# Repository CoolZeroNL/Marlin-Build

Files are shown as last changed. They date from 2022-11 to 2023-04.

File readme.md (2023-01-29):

Build Pipeline for marlin, is currently building from bugfix-2.1.x for the following machines:

- Wanhao dublicator D6
- Wanhao dublicator 4S
- Wanhao dublicator i3 plus
- Wanhao dublicator v2.1
- Creality CR10 S4

# Octoprint - Bed Visualizer
```
G28 X Y               ; home X & Y
M140 S60              ; starting by heating the bed for nominal mesh accuracy
M104 S190             ; heat nozzle
M190 S60              ; waiting until the bed is fully warmed up
M109 S190             ; wait for nozzle to heat up
G28 Z                 ; home Z
M155 S0             ; stop temperature reporting rate to reduce output pollution
@BEDLEVELVISUALIZER	; tell the plugin to watch for reported mesh
G29 T	            ; run bilinear probing
M155 S3             ; reset temperature reporting
M500                  ; store mesh in EEPROM
```

M104 S[extruder[new_tool]_temperature] T[new_tool] 	; warm extruder
M140 S[bed[new_tool] _temperature] 		; warm bed

M109 S[extruder[new_tool]_temperature] T[new_tool] 	; wait extruder to reach temp
M190 S[bed[new_tool] _temperature] 		; wait bed to reach temp

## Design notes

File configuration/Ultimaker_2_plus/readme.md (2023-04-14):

# How to upgrade Firmware
- https://support.makerbot.com/s/article/1667337917778

use cura, also to return to stock firmware.

# Current:

Marlin 1.0.0
Last Updated: Mar 15 2018 13:04:08 | Author: Vers:_3.3.0
Free Memory: 2055  PlannerBufferBytes: 1232
Stored settings retrieved

Steps per unit:
M92 X80.00 Y80.00 Z200.00 E369.00

Maximum feedrates (mm/s):
M203 X300.00 Y300.00 Z40.00 E45.00

Maximum Acceleration (mm/s2):
M201 X9000 Y9000 Z100 E10000

Acceleration: S=acceleration, T=retract acceleration
M204 S3000.00 T3000.00

Advanced variables: S=Min feedrate (mm/s), T=Min travel feedrate (mm/s), B=minimum segment time (ms), X=maximum XY jerk (mm/s),  Z=maximum Z jerk (mm/s),  E=maximum E jerk (mm/s)
M205 S0.00 T0.00 B20000 X20.00 Z0.40 E5.00

Home offset (mm):
M206 X0.00 Y0.00 Z-14.05

PID settings:
M301 P10.03 I1.50 D70.00

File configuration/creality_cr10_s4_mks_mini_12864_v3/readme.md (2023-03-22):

see other CR10 S4 for other details.

# MKS LCD

- https://github.com/makerbase-mks/MKS-MINI12864-V3

## Connect
- Connect to MKS board by EXP1 and EXP2
- Connect to other board by EXP1 and EXP1, but cable need Rotate 180°
- 

## Marlin2.0

in Configuration.h file

``` 
Enable: #define MKS_MINI_12864_V3
Enable: #define NEOPIXEL_LED
Change: #define NEOPIXEL_TYPE NEO_GRBW --> NEO_RGB
``` 

Change color by lcd display on the machine: Lights -> Light Presets

# Z-Offset Instructions:
```
G28 Z       // Home 3D printer
M851 Z0     // Reset Z0Offset
M500        // Store setting to eeprom
M501        // Set active parameters
G28 Z       // Home Z Axis
G1 F60 Z0   // Move nozzle to true 0 offset
M211 S0     // Switch off soft endstops
```

- Move nozzle towards bed slowly until the paper can barely move
- Take note of the Z on the printer display (take that number and add the measurment of the calibration sheet or device used)

```
M851 Z -1.9
M211 S1     // Enable Soft Endstops
M500        // Save settings to Eeprom
M501        // Set Active Parameters
```

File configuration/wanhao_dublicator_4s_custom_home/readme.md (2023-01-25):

# How to flash

Use the atmega 1280 ISP pin headers on the mainboard
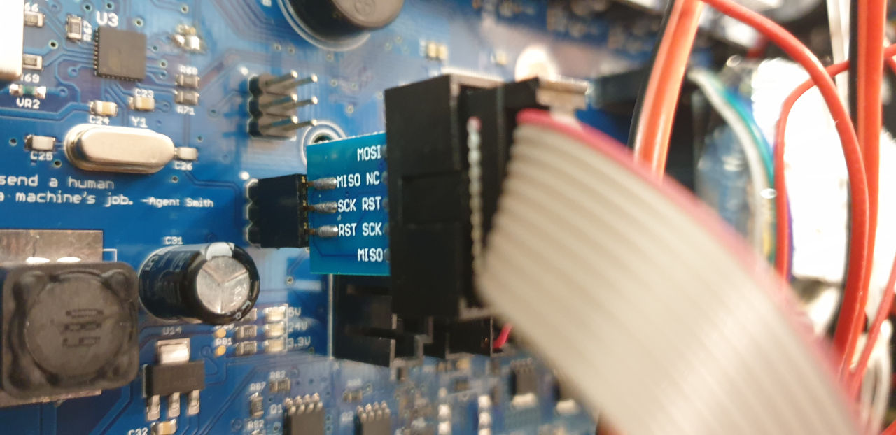
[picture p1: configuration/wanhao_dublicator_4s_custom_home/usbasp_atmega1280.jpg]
This is an image


## Marlin Flash command: 
``` 
avrdude -p m1280 -c usbasp -e -U flash:w:firmware.hex
avrdude -p m1280 -c usbasp -e -U flash:w:firmware_c16d365_c16d3655bf_wanhao_dublicator_4s.hex
```

# Building @ platformm.io
The BOARD_MIGHTYBOARD_REVE is special, it uses pin that are not in the arduino build env. Use build env MightyBoard1280

## Orsinal Sailfish
```
# one 
# Please connect USBASP to motherbaord  8U2  ICSP1
avrdude -p at90usb82 -F -P usb -c usbasp -U lock:w:0x0F:m -U efuse:w:0xF4:m -U hfuse:w:0xD9:m -U lfuse:w:0xff:m -Uflash:w:Makerbot-usbserial.hex

# two
# Connect USBasp to 1280 ICSP2
avrdude -p m1280 -F -P usb -c usbasp -U flash:w:ATmegaBOOT_168_atmega1280.hex -U lfuse:w:0xff:m -U hfuse:w:0xD8:m -U efuse:w:0xF5:m -U lock:w:0x3F:m
```

# WARNING !!
firware is adjuded that the Y MAX LIMIT SWITCH is in the front of the machine, and not on its orginal place!

# USer Fans
NUM_M106_FANS is set to 1, and on build is a custom pins file used!

# Backup of Sailfish settings:

```xml
System Information
 ReplicatorG version: 0040
 Java version: 1.6.0_16

Machine
 Profile Name: The Replicator Dual
 Driver Type: MightyBoard
 Name: Wanhao Duplicatr
 Motherboard firmware version: Unknown v7.7
 Motherboard communication statistics
  Number of packets received from the USB interface:0
  Number of packets sent over the RS485 interface:0
  Number of packets sent over the RS485 interface that were not responded to:0
  Number of packet retries attempted:0
  Number of bytes received over the RS485 interface that were discarded as noise:0

Machine Driver XML:
<machine experimental="0">
		<name>The Replicator Dual</name>
		<geometry type="cartesian">
			<!-- different pulleys on X and Y axii -->
			<axis endstops="max" homingfeedrate="2500" id="x" length="227" maxfeedrate="18000" stepspermm="94.139704"/>  <!-- Pulley dia: 10.82mm / 1/8 step = 1/(10.82 * pi / 1600) -->
			<axis endstops="max" homingfeedrate="2500" id="y" length="148" maxfeedrate="18000" stepspermm="94.139704"/>  <!-- Pulley dia: 10.82mm / 1/8 step = 1/(10.82 * pi / 1600) -->
			<axis endstops="min" homingfeedrate="1100" id="z" length="150" maxfeedrate="1170" stepspermm="400"/> <!-- Actual length is 157mm, we reserve ~5mm for safety. TR-8x8 Z axis = 1/(8/1600) -->
			<axis endstops="none" id="a" length="100000" maxfeedrate="1600" stepspermm="96.275201870333662468889989185642"/> <!-- stepspermm is incoming filament length, see comment at bottom for explanation -->
			<axis endstops="none" id="b" length="100000" maxfeedrate="1600" stepspermm="96.275201870333662468889989185642"/> <!-- stepspermm is incoming filament length, see comment at bottom for explanation -->
		</geometry>
		<tools>
			<tool default_rpm="3" diameter="0.4" fan="true" heatedplatform="false" heater="true" index="1" model="Mk8" motor="true" motor_steps="3200" name="Mk8 Left" stepper_axis="b" type="extruder"/>
			<tool default_rpm="3" diameter="0.4" fan="true" heatedplatform="true" heater="true" index="0" model="Mk8" motor="true" motor_steps="3200" name="Mk8 Right" stepper_axis="a" type="extruder"/>
		</tools>
		<wipes>
			<wipe X1="-135.0" X2="-135.0" Y1="55.0" Y2="45.0" index="0" purge_duration="1000" purge_rpm="5.0" reverse_duration="15" reverse_rpm="35.0" wait="1000.0"/>
			<wipe X1="-135.0" X2="-135.0" Y1="55.0" Y2="45.0" index="1" purge_duration="1000" purge_rpm="5.0" reverse_duration="15" reverse_rpm="35.0" wait="1000.0"/>
		</wipes>
		<offsets>
			<offset xNozzle="33.0" yNozzle="0.0" zNozzle="0.0"/>
		</offsets>
		<clamps/>
		<driver name="mightyboard">
			<!-- optional: <portname>COM1</portname> -->
			<rate>115200</rate>
		</driver>
		<warmup>
		</warmup>
		<cooldown>
M18 (Turn off steppers after a build.)
		</cooldown>
		<bookend dualstart="machines/replicator/Dualstrusion_start.gcode" end="machines/replicator/Dual_Head_end.gcode" start="machines/replicator/Dual_Head_start.gcode"/>
	</machine>
```

        <!-- Dualstrusion_start.gcode -->
        (**** start.gcode for The Replicator, Dualstrusion! ****)
        M103 (disable RPM)
        M73 P0 (enable build progress)
        G21 (set units to mm)
        G90 (set positioning to absolute)
        M109 S110 T0 (set HBP temperature)
        M104 S220 T0 (set extruder temperature)
        M104 S220 T1 (set extruder temperature)
        (**** begin homing ****)
        G162 X Y F2500 (home XY axes maximum)
        G161 Z F1100 (home Z axis minimum)
        G92 Z-5 (set Z to -5)
        G1 Z0.0 (move Z to "0")
        G161 Z F100 (home Z axis minimum)
        M132 X Y Z A B (Recall stored home offsets for XYZAB axis)
        (**** end homing ****)
        G1 X-110.5 Y-74 Z50 F3300.0 (move to waiting position)
        G130 X20 Y20 Z20 A20 B20 (Lower stepper Vrefs while heating)
        M6 T0 (wait for toolhead, and HBP to reach temperature)
        M6 T1 (wait for toolhead, and HBP to reach temperature)
        G130 X127 Y127 Z40 A127 B127 (Set Stepper motor Vref to defaults)
        G0 X-110.5 Y-74     (Position Nozzle)
        G0 Z0.6         (Position Height)
        G1 E4 F50.0      (Create Anchor)
        G92 E0
        (**** end of start.gcode ****)

        <!-- Dual_Head_end.gcode -->
        (******* End.gcode*******)
        M73 P100 ( End  build progress )
        G0 Z150 ( Send Z axis to bottom of machine )
        M18 ( Disable steppers )
        M109 S0 T0 ( Cool down the build platform )
        M104 S0 T0 ( Cool down the Right Extruder )
        M104 S0 T1 ( Cool down the Left Extruder )
        G162 X Y F2500 ( Home XY endstops )
        M18 ( Disable stepper motors )
        M70 P5 ( We <3 Making Things!)
        M72 P1  ( Play Ta-Da song )
        (*********end End.gcode*******)

        <!-- Dual_Head_start.gcode -->
        (**** start.gcode for The Replicator, dual head ****)
        M103 (disable RPM)
        M73 P0 (enable build progress)
        G21 (set units to mm)
        G90 (set positioning to absolute)
        M109 S110 T0 (set HBP temperature)
        M104 S220 T0 (set extruder temperature)
        (**** begin homing ****)
        G162 X Y F2500 (home XY axes maximum)
        G161 Z F1100 (home Z axis minimum)
        G92 Z-5 (set Z to -5)
        G1 Z0.0 (move Z to "0")
        G161 Z F100 (home Z axis minimum)
        M132 X Y Z A B (Recall stored home offsets for XYZAB axis)
        (**** end homing ****)
        G1 X-110.5 Y-74 Z150 F3300.0 (move to waiting position)
        G130 X20 Y20 Z20 A20 B20 (Lower stepper Vrefs while heating)
        M6 T0 (wait for toolhead, and HBP to reach temperature)
        G130 X127 Y127 Z40 A127 B127 (Set Stepper motor Vref to defaults)
        M108 R3.0 T0
        G0 X-110.5 Y-74 (Position Nozzle)
        G0 Z0.6      (Position Height)
        M108 R5.0    (Set Extruder Speed)
        M101         (Start Extruder)
        G4 P2000     (Create Anchor)
        (**** end of start.gcode ****)

        <!-- Single_Head_end.gcode -->
        (******* End.gcode*******)
        M73 P100 ( End  build progress )
        G0 Z150 ( Send Z axis to bottom of machine )
        M18 ( Disable steppers )
        M104 S0 T0 ( Cool down the Right Extruder )
        M109 S0 T0 ( Cool down the platform)
        G162 X Y F2500 ( Home XY endstops )
        M18 ( Disable stepper motors )
        M70 P5 ( We <3 Making Things!)
        M72 P1  ( Play Ta-Da song )
        (*********end End.gcode*******)

        <!-- Single_Head_start.gcode -->
        (**** start.gcode for The Replicator, single head ****)
        M103 (disable RPM)
        M73 P0 (enable build progress)
        G21 (set units to mm)
        G90 (set positioning to absolute)
        M109 S110 T0 (set HBP temperature)
        M104 S220 T0 (set extruder temperature)
        (**** begin homing ****)
        G162 X Y F2500 (home XY axes maximum)
        G161 Z F1100 (home Z axis minimum)
        G92 Z-5 (set Z to -5)
        G1 Z0.0 (move Z to "0")
        G161 Z F100 (home Z axis minimum)
        M132 X Y Z A B (Recall stored home offsets for XYZAB axis)
        (**** end homing ****)
        G1 X-110.5 Y-74 Z150 F3300.0 (move to waiting position)
        G130 X20 Y20 Z20 A20 B20 (Lower stepper Vrefs while heating)
        M6 T0 (wait for toolhead, and HBP to reach temperature)
        G130 X127 Y127 Z40 A127 B127 (Set Stepper motor Vref to defaults)
        M108 R3.0 T0
        G0 X-110.5 Y-74 (Position Nozzle)
        G0 Z0.6      (Position Height)
        M108 R5.0    (Set Extruder Speed)
        M101         (Start Extruder)
        G4 P2000     (Create Anchor)
        (**** end of start.gcode ****)

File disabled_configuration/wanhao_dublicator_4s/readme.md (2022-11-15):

Special note for dual/multi extrusion
By default, Marlin expects the e-steps for each of your extruders to be the same. To work around this, you must compile with DISTINCT_E_FACTORS uncommented/enabled in configuration.h:

You will then be able to enter a unique M92 value for each extruder.

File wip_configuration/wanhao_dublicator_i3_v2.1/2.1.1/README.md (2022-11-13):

Configuration for the Wanhao Duplicator i3 v2.1

[Made by Bot-In-a-Box Educational Robotics](https://botinabox.ca)
[See original configuration repo](https://github.com/BotInABoxER/marlin2-for-wanhao-i3)

Notes:
- YMMV, but the included thermistor table has been tested to work with a 100k bed thermistor with a 10K pull-up resistor
- The smaller Marlin logo is used to save memory
- You may have a 4.7K pull-up resistor, in which case the included thermistor table will be off
- The included thermistor table was generated with `buildroot/share/scripts/createTemperatureLookupMarlin.py --rp=10000`
- Includes an optional custom Wanhao logo bootscreen designed to fit the stock LCD

Inspirations:
- https://www.thingiverse.com/thing:3378807 (Custom firmware 1.x by Nitrogen777)
- https://www.thingiverse.com/thing:3378807 (Custom firmware 2.x by Remotheman)

Some Features:
Built-in Thermal Runway Protection
Change Settings and Save/Load them from EEPROM
Printing over SD Micro/USB Mini Support
Custom Thermistor Table (99) made using buildroot/share/scripts/createTemperatureLookupMarlin.py for 10k pull-up resistor with the out-of-the-box thermistor
Print Time Elapsed and Progress Bar
Minor Stability/Connection/Performance Improvements

Instructions:
- Copy the `Configuration.h`, `_Bootscreen.h` and `Configuration_adv.h` to the `Marlin/ directory`
- Copy the `thermistor_99.h` and `thermistors.h` files to the `Marlin/src/modules/thermistors` directory
- Flash the firmware onto your Melzi (https://www.fission3d.com/guides/flash-bootloader-and-install-firmware-with-raspberry-pi might help)

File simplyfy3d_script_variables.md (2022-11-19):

<!-- https://forum.simplify3d.com/viewtopic.php?t=3144&start=10 -->

<!-- TOC -->

- [Starting script](#starting-script)
- [Ending script](#ending-script)
- [Retraction script](#retraction-script)
- [Tool change script](#tool-change-script)
- [Post processing](#post-processing)

<!-- /TOC -->

# Starting script

A custom G code to be inserted at the very beginning. All speeds should be entered in mm / min.

You can use predefined variables:
| Variable | Comment |
| --- | --- |
| extruder # _temperature | nozzle temperature, where # є [0..5] (only certain ones are substituted, c 4.1 - '-1'); |
| bed # _temperature | table temperature, where # є [0..5] (only certain ones are substituted, c 4.1 - '-1');  |
| fan_speed_percentage | fan speed in percent [0..100]; |
| fan_speed_pwm | fan speed [0..255]; |
| progress | percentage of print (always like 0). |

Since version 4.1, added variables:
| Variable | comment |
| --- | --- |
| current_feature_type | element type, one of (travel, outer_perimeter, inner_perimeter, external_single_extrusion, internal_single_extrusion, gap_fill, solid_layer, infill, bridge, support, dense_support, raft, skirt, prime_pillar, ooze_shield); |
| current_layer | the current layer; |
| current_layer_height | current layer height; |
| current_position_ $ | the current coordinates of the $ axis, where $ є [xyze]; |
| current_position_e # | the current coordinates of the axis of the extruder, where # є [0..5]; |
| next_position_ $ | the following coordinates of the $ axis, where $ є [xyz]; |
| current_tool | current nozzle; |
| first_tool | not clear; |
| last_tool | it is not clear; |
| prime_distance | extrusion distance after retraction; |
| prime_speed | extrusion speed after retraction, mm / min; |
| retract_distance | retraction distance; |
| retract_speed | retraction speed, mm / min; |
| retract_vertical_lift | rising nozzle after retraction; |
| toolchange_prime_distance | extrusion distance after retraction when changing the nozzle; |
| toolchange_prime_speed | extrusion speed after retraction when changing the nozzle, mm / min; |
| toolchange_retract_distance | retraction distance when changing the nozzle; |
| toolchange_retract_speed | retraction speed when changing the nozzle, mm / min; |
| xy_travel_speed | speed of movement along the xy axes, mm / min; |
| z_travel_speed | speed of movement along the z axis, mm / min; |
| travel_speed | travel speed, mm / min; |
| chamber # _temperature | it is not clear where # є [0..5]; |
| fan # _speed_percentage | it is not clear where # є [0..5]; |
| fan # _speed_pwm | it is not clear where # є [0..5]; |
| total_filament_used | length of the used bar; |
| total_filament_weight | weight of the bar used; |
| total_filament_cost | the cost of the used bar; |
| total_filament_volume | the volume of the used bar; |
| total_print_time_min | print time in minutes; |
| total_print_time_sec | print time in seconds; |
| total_layer_count | the number of layers; |
| build_min_ $ | the minimum coordinate of the part along the axis, where $ є [xyz]; |
| build_max_ $ | the maximum coordinate of the part along the axis, where $ є [xyz]; |
| build_size_ $ | the size of the part along the axis, where $ є [xyz]; |
| extruder # _filament_used | the length of the rod used for the extruder, where # є [0..5]; |
| extruder # _filament_weight | the weight of the rod used for the extruder, where # є [0..5]; |
| extruder # _filament_cost | the cost of the rod used for the extruder, where # є [0..5]; |
| extruder # _filament_volume | the volume of the rod used for the extruder, where # є [0..5]. |

Since version 4.1, added operators:
- {EVAL "xxx"} - the number xxx removes the last 0 and then the last '.'. For example, from 10,000 there will be 10, where xxx expression (using QJSEngine.toNumber (), JavaScript code interpreter);
- {IF "xxx"} zzz - when condition xxx is fulfilled, zzz is displayed, where xxx expression (used by QJSEngine.toBool (), JavaScript code interpreter). 

# Ending script

You can use predefined variables:
| Variable | Comment |
| --- | --- |
| current_Z_position | Z coordinates; |
| progress | percentage of print (always like 100). |

Since version 4.1, added variables:
| Variable | Comment |
| --- | --- |
| extruder # _temperature | nozzle temperature or -1, where # є [0..5]; |
| bed # _temperature | table temperature or -1, where # є [0..5]; |
| chamber # _temperature | it is not clear or -1, where # є [0..5]; |
| fan_speed_percentage | fan speed in percent [0..100]; |
| fan_speed_pwm | fan speed [0..255]; |
| fan # _speed_percentage | it is not clear where # є [0..5]; |
| fan # _speed_pwm | it is not clear where # є [0..5]; |
| current_feature_type | element type, one of (travel, outer_perimeter, inner_perimeter, external_single_extrusion, internal_single_extrusion, gap_fill, solid_layer, infill, bridge, support, dense_support, raft, skirt, prime_pillar, ooze_shield); |
| current_layer | the current layer; |
| current_layer_height | current layer height; |
| current_position_ $ | the current coordinates of the $ axis, where $ є [xyze]; |
| current_position_e # | the current coordinates of the axis of the extruder, where # є [0..5]; |
| next_position_ $ | the following coordinates of the $ axis, where $ є [xyz]; |
| current_tool | current nozzle; |
| first_tool | not clear; |
| last_tool | it is not clear; |
| prime_distance | extrusion distance after retraction; |
| prime_speed | extrusion speed after retraction, mm / min; |
| retract_distance | retraction distance; |
| retract_speed | retraction speed, mm / min; |
| retract_vertical_lift | rising nozzle after retraction; |
| toolchange_prime_distance | extrusion distance after retraction when changing the nozzle; |
| toolchange_prime_speed | extrusion speed after retraction when changing the nozzle, mm / min; |
| toolchange_retract_distance | retraction distance when changing the nozzle; |
| toolchange_retract_speed | retraction speed when changing the nozzle, mm / min; |
| xy_travel_speed | speed of movement along the xy axes, mm / min; |
| z_travel_speed | speed of movement along the z axis, mm / min; |
| travel_speed | travel speed, mm / min; |
| total_filament_used | length of the used bar; |
| total_filament_weight | weight of the bar used; |
| total_filament_cost | the cost of the used bar; |
| total_filament_volume | the volume of the used bar; |
| total_print_time_min | print time in minutes; |
| total_print_time_sec | print time in seconds; |
| total_layer_count | the number of layers; |
| build_min_ $ | the minimum coordinate of the part along the axis, where $ є [xyz]; |
| build_max_ $ | the maximum coordinate of the part along the axis, where $ є [xyz]; |
| build_size_ $ | the size of the part along the axis, where $ є [xyz]; |
| extruder # _filament_used | the length of the rod used for the extruder, where # є [0..5]; |
| extruder # _filament_weight | the weight of the rod used for the extruder, where # є [0..5]; |
| extruder # _filament_cost | the cost of the rod used for the extruder, where # є [0..5]; |
| extruder # _filament_volume | the volume of the rod used for the extruder, where # є [0..5]. |

Since version 4.1, added operators:
- {EVAL "xxx"} - the number xxx removes the last 0 and then the last '.'. For example, from 10,000 there will be 10, where xxx expression (using QJSEngine.toNumber (), JavaScript code interpreter);
- {IF "xxx"} zzz - when condition xxx is fulfilled, zzz is displayed, where xxx expression (used by QJSEngine.toBool (), JavaScript code interpreter). 

# Retraction script

The following operators are supported:

- {EVAL "xxx"} - the number xxx removes the last 0 and then the last '.'. For example, from 10,000 there will be 10 (updated from version 4.1);
- {IF xxxOPyyy} zzz - when the condition is met, zzz is displayed (updated from version 4.1), where

    - OP - operation, one of (==,! =, <, <=,>,> =, =);
    - xxx may be:
    - TOOL - nozzle number, then yyy must be a number [0..5]
    - FEATURETYPE - element type, then yyy must be one of (travel, outer_perimeter, inner_perimeter, external_single_extrusion, internal_single_extrusion, gap_fill, solid_layer, infill, bridge, support, dense_support, raft, skirt, prime_pillar, ooze_shield)

You can use predefined variables:
| Variable | Comment |
| --- | --- |
| retract_distance | retraction distance; |
| prime_distance | extrusion distance after retraction; |
| retract_speed | retraction speed; |
| travel_speed | speed of movement; |
| current_position_ $ | the current coordinates of the $ axis, where $ є [xyz]; |
| next_position_ $ | the following coordinates of the $ axis, where $ є [xyz]; |
| previous_direction_ $ | previous shift of the $ axis, where $ є [xyz] (removed from version 4.1); |
| next_direction_ $ | the next shift of the $ axis, where $ є [xyz] (removed from version 4.1); |
| average_direction_ $  | not clear (removed from version 4.1). |

Since version 4.1, added variables:
| Variable | Comment |
| --- | --- |
| extruder # _temperature | nozzle temperature or -1, where # є [0..5]; |
| bed # _temperature | table temperature or -1, where # є [0..5]; |
| chamber # _temperature | it is not clear or -1, where # є [0..5]; |
| fan_speed_percentage | fan speed in percent [0..100]; |
| fan_speed_pwm | fan speed [0..255]; |
| fan # _speed_percentage | it is not clear where # є [0..5]; |
| fan # _speed_pwm | it is not clear where # є [0..5]; |
| current_feature_type | element type, one of (travel, outer_perimeter, inner_perimeter, external_single_extrusion, internal_single_extrusion, gap_fill, solid_layer, infill, bridge, support, dense_support, raft, skirt, prime_pillar, ooze_shield); |
| current_layer | the current layer; |
| current_layer_height] current layer height; | |
| current_position_e # | the current coordinates of the axis of the extruder, where # є [0..5]; |
| current_tool | current nozzle; |
| first_tool | not clear; |
| last_tool | it is not clear; |
| prime_speed | extrusion speed after retraction, mm / min; |
| retract_vertical_lift | rising nozzle after retraction; |
| toolchange_prime_distance | extrusion distance after retraction when changing the nozzle; |
| toolchange_prime_speed | extrusion speed after retraction when changing the nozzle, mm / min; |
| toolchange_retract_distance | retraction distance when changing the nozzle; |
| toolchange_retract_speed | retraction speed when changing the nozzle, mm / min; |
| xy_travel_speed | speed of movement along the xy axes, mm / min; |
| z_travel_speed | speed of movement along the z axis, mm / min; |
| progress | percentage of print; |
| total_filament_used | length of the used bar; |
| total_filament_weight | weight of the bar used; |
| total_filament_cost | the cost of the used bar; |
| total_filament_volume | the volume of the used bar; |
| total_print_time_min | print time in minutes; |
| total_print_time_sec | print time in seconds; |
| total_layer_count | the number of layers; |
| build_min_ $ | the minimum coordinate of the part along the axis, where $ є [xyz]; |
| build_max_ $ | the maximum coordinate of the part along the axis, where $ є [xyz]; |
| build_size_ $ | the size of the part along the axis, where $ є [xyz]; |
| extruder # _filament_used | the length of the rod used for the extruder, where # є [0..5]; |
| extruder # _filament_weight | the weight of the rod used for the extruder, where # є [0..5]; |
| extruder # _filament_cost | the cost of the rod used for the extruder, where # є [0..5]; |
| extruder # _filament_volume | the volume of the rod used for the extruder, where # є [0..5]. |

Since version 4.1, added operators:
- {EVAL "xxx"} - the number xxx removes the last 0 and then the last '.'. For example, from 10,000 there will be 10, where xxx expression (using QJSEngine.toNumber (), JavaScript code interpreter);
- {IF "xxx"} zzz - when condition xxx is fulfilled, zzz is displayed, where xxx expression (used by QJSEngine.toBool (), JavaScript code interpreter).

# Tool change script

The following operators are supported:

- {IF xxxOPyyy} zzz - when the condition is met, zzz is displayed (updated from version 4.1), where

    - OP - operation, one of (==,! =, <, <=,>,> =, =);
    
    - xxx may be:
    - OLDTOOL - No. of the previous nozzle, then yyy must be a number [0..5]
    - NEWTOOL - No. of the new nozzle, then yyy must be a number [0..5]
    - FEATURETYPE - element type, then yyy must be one of (travel, outer_perimeter, inner_perimeter, external_single_extrusion, internal_single_extrusion, gap_fill, solid_layer, infill, bridge, support, dense_support, raft, skirt, prime_pillar, ooze_shield)

You can use predefined variables:
| Variable | Comment |
| --- | --- |
| new_tool | No. of the new nozzle; |
| old_tool | number of the previous nozzle; |
| travel_speed | speed of movement; |
| toolchange_retract_speed | retraction speed when changing the nozzle; |
| toolchange_retract_distance | retraction distance when changing the nozzle; |
| toolchange_prime_distance | extrusion distance after retraction when changing the nozzle; |
| extruder # _temperature | nozzle temperature, where # є [0..5]; |
| bed # _temperature | temperature of the table, where # є [0..5]; |
| current_position_ $ | the current coordinates of the $ axis, where $ є [XYZ]; |
| next_position_ $ | the following coordinates of the $ axis, where $ є [XYZ]; |
| previous_direction_ $ | previous shift of the $ axis, where $ є [XYZ] (removed from version 4.1); |
| next_direction_ $ | the next shift of the $ axis, where $ є [XYZ] (removed from version 4.1); |
| average_direction_ $ | not clear (removed from version 4.1). |

Since version 4.1, added variables:
| Variable | Comment |
| --- | --- |
| chamber # _temperature | it is not clear or -1, where # є [0..5]; |
| fan_speed_percentage | fan speed in percent [0..100]; |
| fan_speed_pwm | fan speed [0..255]; |
| fan # _speed_percentage | it is not clear where # є [0..5]; |
| fan # _speed_pwm | it is not clear where # є [0..5]; |
| current_feature_type | element type, one of (travel, outer_perimeter, inner_perimeter, external_single_extrusion, internal_single_extrusion, gap_fill, solid_layer, infill, bridge, support, dense_support, raft, skirt, prime_pillar, ooze_shield); |
| current_layer | the current layer; |
| current_layer_height] current layer height; | |
| current_position_e # | the current coordinates of the axis of the extruder, where # є [0..5]; |
| current_tool | current nozzle; |
| first_tool | not clear; |
| first_tool_use | not clear; |
| last_tool | it is not clear; |
| prime_distance | extrusion distance after retraction; |
| prime_speed | extrusion speed after retraction, mm / min; |
| retract_distance | retraction distance; |
| retract_speed | retraction speed, mm / min; |
| retract_vertical_lift | rising nozzle after retraction; |
| toolchange_prime_speed | extrusion speed after retraction when changing the nozzle, mm / min; |
| xy_travel_speed | speed of movement along the xy axes, mm / min; |
| z_travel_speed | speed of movement along the z axis, mm / min; |
| progress | percentage of print; |
| total_filament_used | length of the used bar; |
| total_filament_weight | weight of the bar used; |
| total_filament_cost | the cost of the used bar; |
| total_filament_volume | the volume of the used bar; |
| total_print_time_min | print time in minutes; |
| total_print_time_sec | print time in seconds; |
| total_layer_count | the number of layers; |
| build_min_ $ | the minimum coordinate of the part along the axis, where $ є [xyz]; |
| build_max_ $ | the maximum coordinate of the part along the axis, where $ є [xyz]; |
| build_size_ $ | the size of the part along the axis, where $ є [xyz]; |
| extruder # _filament_used | the length of the rod used for the extruder, where # є [0..5]; |
| extruder # _filament_weight | the weight of the rod used for the extruder, where # є [0..5]; |
| extruder # _filament_cost | the cost of the rod used for the extruder, where # є [0..5]; |
| extruder # _filament_volume | the volume of the rod used for the extruder, where # є [0..5]. |

Since version 4.1, added operators:
- {EVAL "xxx"} - the number xxx removes the last 0 and then the last '.'. For example, from 10,000 there will be 10, where xxx expression (using QJSEngine.toNumber (), JavaScript code interpreter);
- {IF "xxx"} zzz - when condition xxx is fulfilled, zzz is displayed, where xxx expression (used by QJSEngine.toBool (), JavaScript code interpreter). 

# Post processing
Running scripts after creating the G-code file. For example, "notepad.exe" "[output_filepath]" You can use system variables (% programfiles%,% windir%, etc.) and predefined:
| Variable | Comment |
| --- | --- |
| output_filename | file name without extension; |
| output_filepath | the name of the file with the directory; |
| output_dir | file directory; |
| install_dir | dir |

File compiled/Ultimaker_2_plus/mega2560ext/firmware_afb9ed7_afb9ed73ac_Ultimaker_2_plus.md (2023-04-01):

https://github.com/MarlinFirmware/Marlin/afb9ed73ac

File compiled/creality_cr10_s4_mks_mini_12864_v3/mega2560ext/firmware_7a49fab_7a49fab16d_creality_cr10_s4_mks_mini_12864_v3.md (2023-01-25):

https://github.com/MarlinFirmware/Marlin/7a49fab16d

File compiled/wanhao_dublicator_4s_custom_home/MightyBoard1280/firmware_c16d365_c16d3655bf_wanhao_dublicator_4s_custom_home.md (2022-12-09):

https://github.com/MarlinFirmware/Marlin/c16d3655bf

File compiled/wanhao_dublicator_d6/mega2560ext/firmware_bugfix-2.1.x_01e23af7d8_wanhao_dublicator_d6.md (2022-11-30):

https://github.com/MarlinFirmware/Marlin/01e23af7d8

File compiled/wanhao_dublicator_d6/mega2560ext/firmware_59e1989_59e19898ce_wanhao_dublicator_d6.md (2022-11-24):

https://github.com/MarlinFirmware/Marlin/59e19898ce

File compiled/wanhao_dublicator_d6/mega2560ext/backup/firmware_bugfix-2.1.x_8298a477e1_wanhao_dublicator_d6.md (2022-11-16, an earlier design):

https://github.com/MarlinFirmware/Marlin/tree/8298a477e1

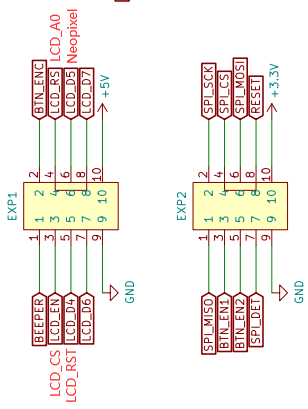
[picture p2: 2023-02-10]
configuration/creality_cr10_s4_mks_mini_12864_v3/MKS_MINI12864_V3_PINOUT.png

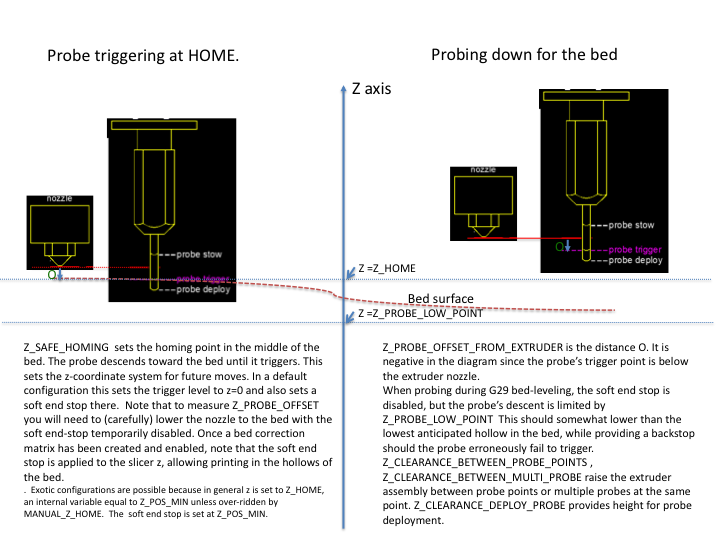
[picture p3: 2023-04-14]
64058068-4a37e280-cb41-11e9-93ad-2ba1b37446d4.png

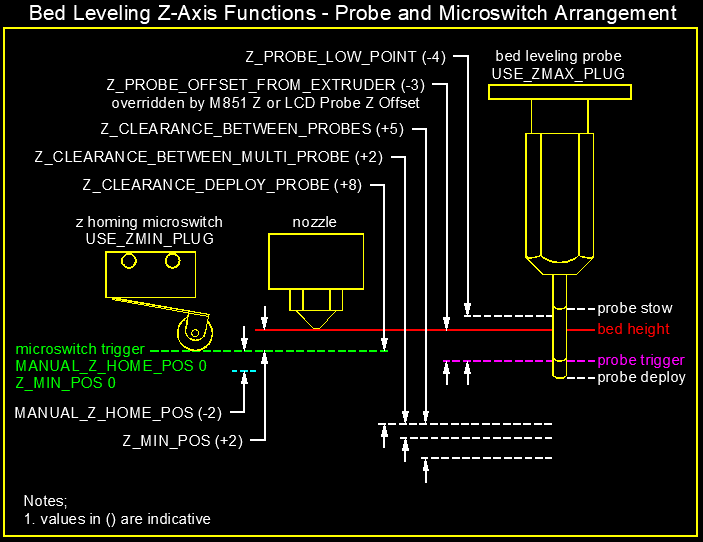
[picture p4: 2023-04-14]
64071215-0b349900-ccc9-11e9-9708-3c4149badca7.png

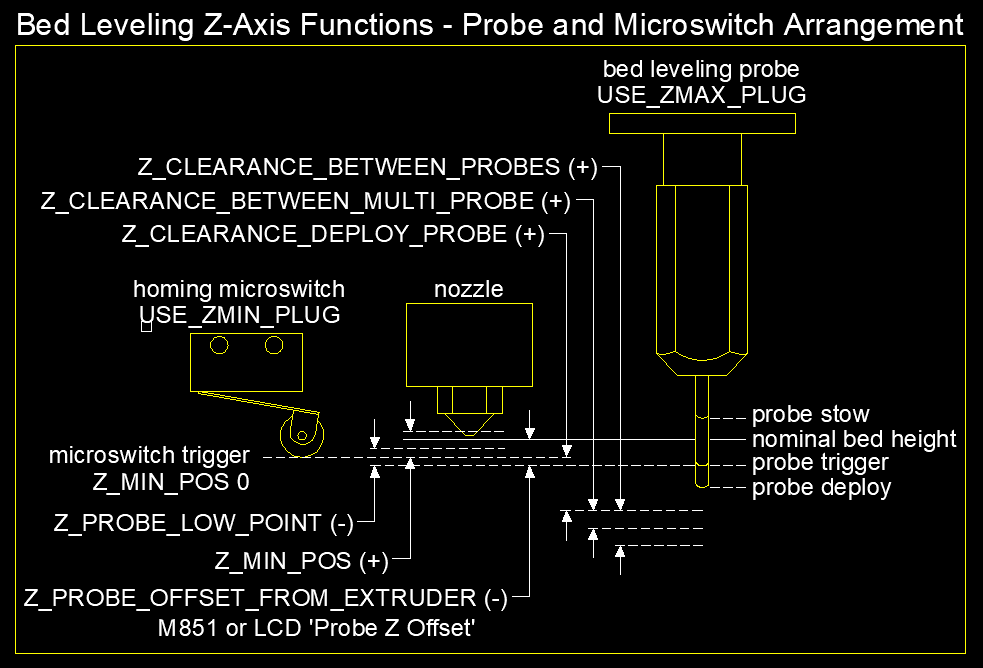
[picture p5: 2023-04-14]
63824484-6dc92480-c9ab-11e9-8d31-c03eaba64a8f.png

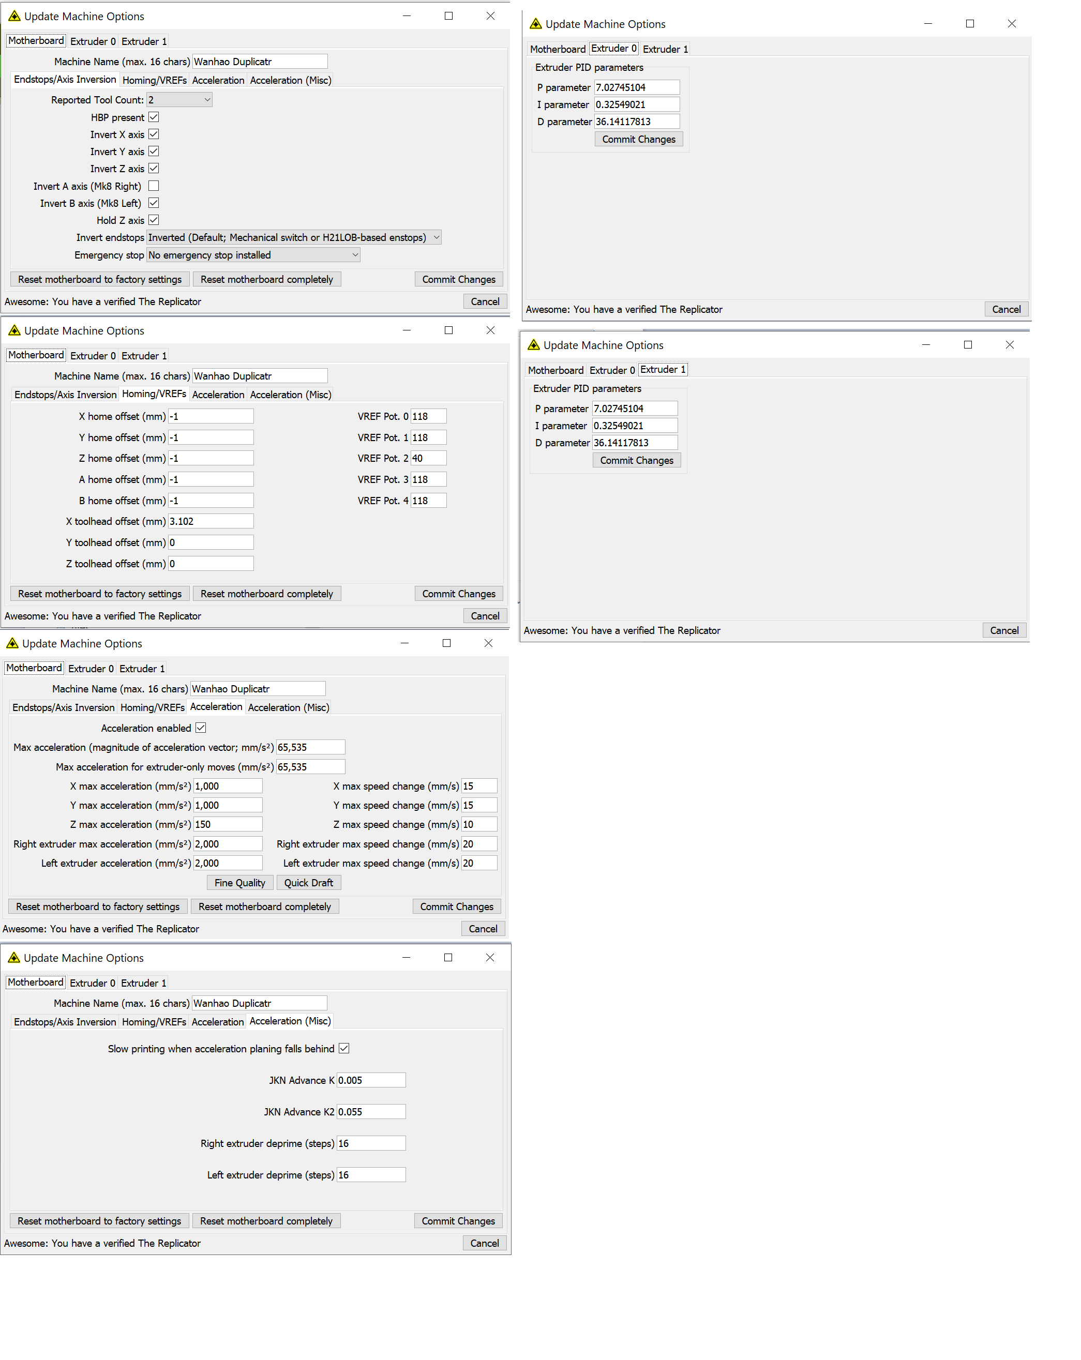
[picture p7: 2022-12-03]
configuration/wanhao_dublicator_4s_custom_home/machine-options.png

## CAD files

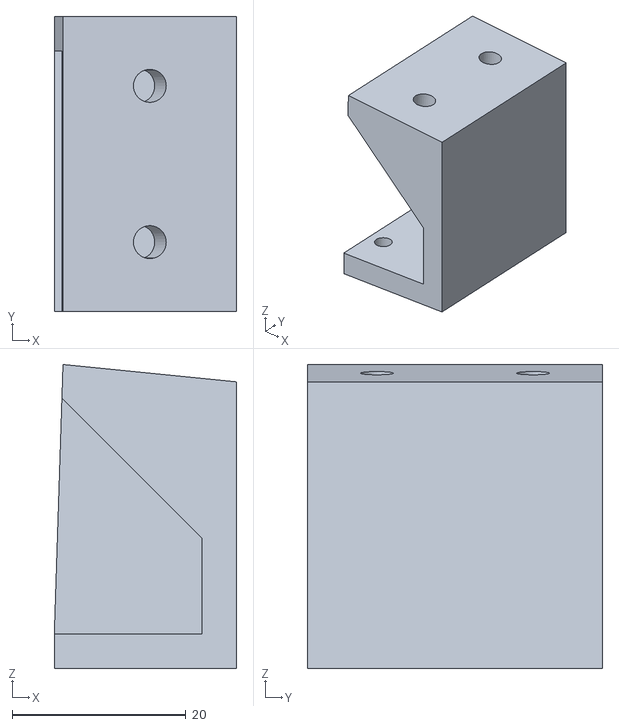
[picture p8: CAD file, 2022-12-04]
configuration/wanhao_dublicator_4s_custom_home/Wanhao-dub-D6-switchholder v3.stl
21.0 x 34.0 x 35.0

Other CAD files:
configuration/wanhao_dublicator_4s_custom_home/Wanhao-dub-D6-switchholder v3.f3d

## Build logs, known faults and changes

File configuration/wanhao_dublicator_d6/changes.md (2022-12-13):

# Configuration.h

| 2.0 | 2.1.1 | |
| --- | --- | --- |
| | #define SWITCHING_NOZZLE_SERVO_DWELL 2500 | // Dwell time to wait for servo to make physical move |
| #define DEFAULT_EJERK 5.0 | #define DEFAULT_EJERK 1.0 | // May be used by Linear Advance |
| #define S_CURVE_ACCELERATION | //#define S_CURVE_ACCELERATION | // This option eliminates vibration during printing by fitting a Bézier curve to move acceleration, producing much smoother direction changes. |
| #define LEVEL_BED_CORNERS | //#define LEVEL_BED_CORNER | // Add a menu item to move between bed corners for manual bed adjustment |
| #define XY_SKEW_FACTOR 0.0 | //#define XY_SKEW_FACTOR 0.0 | // Or, set the XY skew factor directly |
| | #define Z_HOMING_HEIGHT  0 | // (mm) Minimal Z height before homing (G28) for Z clearance above the bed, clamps, |
| | | |

## Tuning
|2.0 |2.1.1 | old 2.1.1 value |
|---|---|---|-|
| #define DEFAULT_MAX_FEEDRATE { 250, 250, 5, 25 } | #define DEFAULT_MAX_FEEDRATE { 300, 300, 5, 25 } | |
| #define DEFAULT_MAX_ACCELERATION { 750, 750, 100, 500 } | #define DEFAULT_MAX_ACCELERATION { 3000, 3000, 100, 500 } | |// X, Y, Z, E0 ... Maximum start speed for accelerated moves
| #define DEFAULT_ACCELERATION 800 | #define DEFAULT_ACCELERATION 1000 | 1500 |// X, Y, Z ... and E acceleration for printing moves
| #define DEFAULT_RETRACT_ACCELERATION  500 | #define DEFAULT_RETRACT_ACCELERATION  800 | 1500 |// E acceleration for retracts
| #define DEFAULT_TRAVEL_ACCELERATION 1000 | #define DEFAULT_TRAVEL_ACCELERATION 1500 | 3000 |// X, Y, Z ... acceleration for travel (non printing) moves
| #define DEFAULT_AXIS_STEPS_PER_UNIT { 80.0395, 80.0395, 400.48, 99.1 } | #define DEFAULT_AXIS_STEPS_PER_UNIT { 80.0395, 80.0395, 400.48, 104.31579 } | |

# Configuration_adv.h

|2.0 |2.1.1 | |
|---|---|-|
| #define WATCH_TEMP_PERIOD 90 | #define WATCH_TEMP_PERIOD  40 | // Whenever an M104, M109, or M303 increases the target temperature, the firmware will wait for the WATCH_TEMP_PERIOD to expire. If the temperature hasn't increased by WATCH_TEMP_INCREASE degrees, the machine is halted and requires a hard reset.
| #define Z_STEPPER_ALIGN_ITERATIONS 5 | #define Z_STEPPER_ALIGN_ITERATIONS 3 | // Number of iterations to apply during alignment
| #define ADAPTIVE_STEP_SMOOTHING | //#define ADAPTIVE_STEP_SMOOTHING | // Adaptive Step Smoothing increases the resolution of multi-axis moves, particularly at step frequencies below 1kHz (for AVR) or 10kHz (for ARM), where aliasing between axes in multi-axis moves causes audible vibration and surface artifacts
| #define PWM_MOTOR_CURRENT { 1000, 900, 900 } | #define PWM_MOTOR_CURRENT { 1200, 1200, 1000 } | // Values in milliamps
| #define MANUAL_FEEDRATE { 50*60, 50*60, 4*60, 60 } | #define MANUAL_FEEDRATE { 70*60, 70*60, 15*60, 6*60 } | // Feedrates for manual moves along X, Y, Z, E from panel
| #define SD_FINISHED_RELEASECOMMAND "M84 X Y Z E" | #define SD_FINISHED_RELEASECOMMAND "M84" | // Use "M84XYE" to keep Z enabled so your bed stays in place
| #define POWER_LOSS_RECOVERY | //#define POWER_LOSS_RECOVERY | // Store the current state to the SD Card at the start of each layer during SD printing.
| #define BABYSTEP_MULTIPLICATOR_Z  5 | #define BABYSTEP_MULTIPLICATOR_Z  1 | // (steps or mm) Steps or millimeter distance for each Z babystep
| #define MOVE_Z_WHEN_IDLE | //#define MOVE_Z_WHEN_IDLE | // Jump to the move Z menu on doubleclick when printer is idle.
| #define EMERGENCY_PARSER | //#define EMERGENCY_PARSER | // Add a low-level parser to intercept certain commands as they * enter the serial receive buffer, so they cannot be blocked. * Currently handles M108, M112, M410, M876
| //#define HOST_ACTION_COMMANDS | #define HOST_ACTION_COMMANDS | // Host Prompt Support enables Marlin to use the host for user prompts so filament runout and other processes can be managed from the host side.

# Home clearing

We leave our bed at the bottom of the printer when the print is done. But any homeing will raise the bed x lower and then do the homing. We dont want this beheaver, so we disable this.

configuration.h

from:
// #define Z_HOMING_HEIGHT  4      // (mm) Minimal Z height before homing (G28) for Z clearance above the bed, clamps, ...
                                  // Be sure to have this much clearance over your Z_MAX_POS to prevent grinding.

to
#define Z_HOMING_HEIGHT  0      // (mm) Minimal Z height before homing (G28) for Z clearance above the bed, clamps, ...
                                  // Be sure to have this much clearance over your Z_MAX_POS to prevent grinding.

# Not working:

    - Stop print trough menu, when print is started from simplyfy3d (HOST_ACTION_COMMANDS is enabled)
    - Custom menu label 1 not working, shows only pla

# Calubration:
https://teachingtechyt.github.io/calibration.html#esteps

## Extruder E-steps Calibration:

    M92: X80.04 Y80.04 Z400.48 E99.10
    
    New: E = 104.31579

## PID

    ; Hotend PID:
    M301 P9.12 I0.41 D50.98

    New:

        READ: #define DEFAULT_Kp 19.09
        READ: #define DEFAULT_Ki 0.92
        READ: #define DEFAULT_Kd 99.38

    ; Bed PID:
    M304 P124.55 I23.46 D165.29

    New:
    
        #define DEFAULT_bedKp 30.02
        #define DEFAULT_bedKi 5.16
        #define DEFAULT_bedKd 116.41

# Strange errors:

## busy: processing
Unknown command: "P0 B2G1 X92.000 Y84.500 E0.8042"

Unknown command: "Gok P0 248 Y100.651 E0.0028 F1750"
WARNING: Firmware unresponsive.  Attempting to force continue...

WARNING: Firmware unresponsive.  Attempting to force continue...
Unknown command: "ok P142 Y134.696 E0.0673 F2625

Attempting connection at \\.\COM5...
READ: start
  Connected to machine!
Last Updated: 2022-11-15 | Author: (CoolZeroNL, default config)
Compiled: Nov 30 2022
Free Memory: 2928  PlannerBufferBytes: 1344
V87 stored settings retrieved (626 bytes; crc 46077)
SD card released
Unknown command: "MeM105"

Unknown command: "ok P45.775 Y68.912 F6600"
busy: processing
Unknown command: "1 X184.001 Y103.705 E0.0110 F2800"

Unknown command: "ok P3 B482 Y65.702 E0.0072 F1750"
Unknown command: "ok P0 B714 Y143.023 E0.1339 F3500"
Unknown command: "P0 B3"
Unknown command: "4.430 Y50.149 E0.0046 F2625"
Unknown command: "0 B2"
Unknown command: "92.505 Y16.183 E0.0102"
Unknown command: "9"
Unknown command: "ok P0 000"
Unknown command: "57"
Unknown command: "ok P0816 Y45.279 E0.1075"

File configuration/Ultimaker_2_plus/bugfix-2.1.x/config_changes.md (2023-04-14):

./configuration/Ultimaker_2_plus/bugfix-2.1.x/Configuration.h:#define STRING_CONFIG_H_AUTHOR "(CoolZeroNL, default config)" // Who made the changes.    // JHG
./configuration/Ultimaker_2_plus/bugfix-2.1.x/Configuration.h:    // #define DEFAULT_Kp   10.03  // JHG - 8.86
./configuration/Ultimaker_2_plus/bugfix-2.1.x/Configuration.h:    // #define DEFAULT_Ki   1.5    // JHG - 0.68
./configuration/Ultimaker_2_plus/bugfix-2.1.x/Configuration.h:    // #define DEFAULT_Kd   70     // JHG - 28.86
./configuration/Ultimaker_2_plus/bugfix-2.1.x/Configuration.h:    // #define DEFAULT_Kp 9.46     // JHG - PID tuned
./configuration/Ultimaker_2_plus/bugfix-2.1.x/Configuration.h:    // #define DEFAULT_Ki 0.76     // JHG - PID tuned
./configuration/Ultimaker_2_plus/bugfix-2.1.x/Configuration.h:    // #define DEFAULT_Kd 29.65    // JHG - PID tuned
./configuration/Ultimaker_2_plus/bugfix-2.1.x/Configuration.h:    #define DEFAULT_Kp 10.38      // JHG - PID tuned - fan 100%
./configuration/Ultimaker_2_plus/bugfix-2.1.x/Configuration.h:    #define DEFAULT_Ki 0.85       // JHG - PID tuned - fan 100%
./configuration/Ultimaker_2_plus/bugfix-2.1.x/Configuration.h:    #define DEFAULT_Kd 31.69      // JHG - PID tuned - fan 100%
./configuration/Ultimaker_2_plus/bugfix-2.1.x/Configuration.h:  #define DEFAULT_bedKp 28.22     // JHG - PID tuned
./configuration/Ultimaker_2_plus/bugfix-2.1.x/Configuration.h:  #define DEFAULT_bedKi 4.85      // JHG - PID tuned
./configuration/Ultimaker_2_plus/bugfix-2.1.x/Configuration.h:  #define DEFAULT_bedKd 109.41    // JHG - PID tuned
./configuration/Ultimaker_2_plus/bugfix-2.1.x/Configuration.h:#define USE_YMAX_PLUG   // JHG - switch is in the back, so max position
./configuration/Ultimaker_2_plus/bugfix-2.1.x/Configuration.h:#define USE_ZMAX_PLUG   // JHG - switch is in bottom, so max position
./configuration/Ultimaker_2_plus/bugfix-2.1.x/Configuration.h:// #define DEFAULT_MAX_FEEDRATE          { 500, 500, 40, 45 }      // JHG - match speed to org config of the machine
./configuration/Ultimaker_2_plus/bugfix-2.1.x/Configuration.h:#define DEFAULT_MAX_FEEDRATE          { 300, 300, 40, 45 }      // JHG - match speed to org config of the machine
./configuration/Ultimaker_2_plus/bugfix-2.1.x/Configuration.h:#define Y_HOME_DIR 1     // JHG - Homing is now moving to the front, switch is in the back
./configuration/Ultimaker_2_plus/bugfix-2.1.x/Configuration.h:#define Z_HOME_DIR 1     // JHG - Homing is now moving to the top, switch is in the bottom
./configuration/Ultimaker_2_plus/bugfix-2.1.x/Configuration.h:#define X_BED_SIZE 223      // JHG - 220 to 223.0 cura profile size
./configuration/Ultimaker_2_plus/bugfix-2.1.x/Configuration.h:#define Y_BED_SIZE 223      // JHG - 220 to 223.0 cura profile size
./configuration/Ultimaker_2_plus/bugfix-2.1.x/Configuration.h:#define Z_MAX_POS 210     // JHG - 210 also fits beter for MESH homing.
./configuration/Ultimaker_2_plus/bugfix-2.1.x/Configuration_adv.h:  #define CASE_LIGHT_DEFAULT_ON true          // JHG - Set default power-up state on
./configuration/Ultimaker_2_plus/bugfix-2.1.x/Configuration_adv.h:  #define CASE_LIGHT_DEFAULT_BRIGHTNESS 52    // JHG - 20% - Set default power-up brightness (0-255, requires PWM pin)

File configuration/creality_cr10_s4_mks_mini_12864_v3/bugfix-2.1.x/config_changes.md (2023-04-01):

./configuration/creality_cr10_s4_mks_mini_12864_v3/bugfix-2.1.x/Configuration.h:#define BAUDRATE 250000     //JHG
./configuration/creality_cr10_s4_mks_mini_12864_v3/bugfix-2.1.x/Configuration.h:#define DEFAULT_NOMINAL_FILAMENT_DIA 3  // JHG
./configuration/creality_cr10_s4_mks_mini_12864_v3/bugfix-2.1.x/Configuration.h:    #define DEFAULT_Kp  29.89       // JHG
./configuration/creality_cr10_s4_mks_mini_12864_v3/bugfix-2.1.x/Configuration.h:    #define DEFAULT_Ki   2.79       // JHG
./configuration/creality_cr10_s4_mks_mini_12864_v3/bugfix-2.1.x/Configuration.h:    #define DEFAULT_Kd  80.19       // JHG
./configuration/creality_cr10_s4_mks_mini_12864_v3/bugfix-2.1.x/Configuration.h:#define PIDTEMPBED  // JHG --> disabled big-bang will not be able to go higher then 75 degree
./configuration/creality_cr10_s4_mks_mini_12864_v3/bugfix-2.1.x/Configuration.h:  // #define DEFAULT_bedKp 185.12                          // JHG
./configuration/creality_cr10_s4_mks_mini_12864_v3/bugfix-2.1.x/Configuration.h:  // #define DEFAULT_bedKi 36.99                           // JHG
./configuration/creality_cr10_s4_mks_mini_12864_v3/bugfix-2.1.x/Configuration.h:  // #define DEFAULT_bedKd 617.69                          // JHG
./configuration/creality_cr10_s4_mks_mini_12864_v3/bugfix-2.1.x/Configuration.h:  #define DEFAULT_bedKp 150.53                          // JHG
./configuration/creality_cr10_s4_mks_mini_12864_v3/bugfix-2.1.x/Configuration.h:  #define DEFAULT_bedKi 18.75                           // JHG
./configuration/creality_cr10_s4_mks_mini_12864_v3/bugfix-2.1.x/Configuration.h:  #define DEFAULT_bedKd 805.63                          // JHG
./configuration/creality_cr10_s4_mks_mini_12864_v3/bugfix-2.1.x/Configuration.h:#define Z_MIN_ENDSTOP_INVERTING false       // Set to true to invert the logic of the endstop.   // JHG
./configuration/creality_cr10_s4_mks_mini_12864_v3/bugfix-2.1.x/Configuration.h:#define Z_MIN_PROBE_ENDSTOP_INVERTING false // Set to true to invert the logic of the probe.     // JHG 3d touch
./configuration/creality_cr10_s4_mks_mini_12864_v3/bugfix-2.1.x/Configuration.h:// #define Z_MIN_ENDSTOP_INVERTING true       // Set to true to invert the logic of the endstop.   // JHG
./configuration/creality_cr10_s4_mks_mini_12864_v3/bugfix-2.1.x/Configuration.h:// #define Z_MIN_PROBE_ENDSTOP_INVERTING true // Set to true to invert the logic of the probe.     // JHG NPN-type sensor
./configuration/creality_cr10_s4_mks_mini_12864_v3/bugfix-2.1.x/Configuration.h:#define DEFAULT_AXIS_STEPS_PER_UNIT   { 80, 80, 400, 485 }      // Bulldog XL extruder              // JHG
./configuration/creality_cr10_s4_mks_mini_12864_v3/bugfix-2.1.x/Configuration.h:#define DEFAULT_MAX_FEEDRATE          { 300, 300, 5, 50 }       // JHG
./configuration/creality_cr10_s4_mks_mini_12864_v3/bugfix-2.1.x/Configuration.h:// #define DEFAULT_MAX_ACCELERATION      { 300, 300, 100, 1000 } // --> org // JHG
./configuration/creality_cr10_s4_mks_mini_12864_v3/bugfix-2.1.x/Configuration.h:  // #define DEFAULT_XJERK  5.0  // JHG
./configuration/creality_cr10_s4_mks_mini_12864_v3/bugfix-2.1.x/Configuration.h:  #define DEFAULT_XJERK  10.0  // JHG
./configuration/creality_cr10_s4_mks_mini_12864_v3/bugfix-2.1.x/Configuration.h:  #define DEFAULT_YJERK  10.0  // JHG
./configuration/creality_cr10_s4_mks_mini_12864_v3/bugfix-2.1.x/Configuration.h:  // #define DEFAULT_YJERK  5.0  // JHG
./configuration/creality_cr10_s4_mks_mini_12864_v3/bugfix-2.1.x/Configuration.h:// #define FIX_MOUNTED_PROBE     // JHG --> disable BLTOUCH
./configuration/creality_cr10_s4_mks_mini_12864_v3/bugfix-2.1.x/Configuration.h:#define BLTOUCH // JHG  --> disable FIX_MOUNTED_PROBE
./configuration/creality_cr10_s4_mks_mini_12864_v3/bugfix-2.1.x/Configuration.h:#define NOZZLE_TO_PROBE_OFFSET { 31.5, 0, -2.125 }  // JHG
./configuration/creality_cr10_s4_mks_mini_12864_v3/bugfix-2.1.x/Configuration.h:#define PROBING_MARGIN 10 // JHG -> adusted the bed size, and Y limit switch moved to the front by x mm
./configuration/creality_cr10_s4_mks_mini_12864_v3/bugfix-2.1.x/Configuration.h:#define RESTORE_LEVELING_AFTER_G28  // JHG
./configuration/creality_cr10_s4_mks_mini_12864_v3/bugfix-2.1.x/Configuration.h:  #define GRID_MAX_POINTS_X 6                       //JHG
./configuration/creality_cr10_s4_mks_mini_12864_v3/bugfix-2.1.x/Configuration.h:#define Z_SAFE_HOMING // JHG
./configuration/creality_cr10_s4_mks_mini_12864_v3/bugfix-2.1.x/Configuration.h:#define REVERSE_ENCODER_DIRECTION // JHG  - right turn needs to be + value, 
./configuration/creality_cr10_s4_mks_mini_12864_v3/bugfix-2.1.x/Configuration.h:// #define REPRAP_DISCOUNT_FULL_GRAPHIC_SMART_CONTROLLER  // JHG - Disbaled CR10 orginal LCD
./configuration/creality_cr10_s4_mks_mini_12864_v3/bugfix-2.1.x/Configuration.h:#define MKS_MINI_12864_V3   // JHG
./configuration/creality_cr10_s4_mks_mini_12864_v3/bugfix-2.1.x/Configuration.h:#define NEOPIXEL_LED  // JHG
./configuration/creality_cr10_s4_mks_mini_12864_v3/bugfix-2.1.x/Configuration.h:  #define NEOPIXEL_TYPE             NEO_RGB // NEO_GRBW, NEO_RGBW, NEO_GRB, NEO_RBG, etc.    // JHG
./configuration/creality_cr10_s4_mks_mini_12864_v3/bugfix-2.1.x/Configuration.h:  #define NEOPIXEL_PIXELS              3 // Number of LEDs in the strip. (Longest strip when NEOPIXEL2_SEPARATE is disabled.) // JHG
./configuration/creality_cr10_s4_mks_mini_12864_v3/bugfix-2.1.x/Configuration.h:  // #define NEOPIXEL_STARTUP_TEST         // Cycle through colors at startup  // JHG
./configuration/creality_cr10_s4_mks_mini_12864_v3/bugfix-2.1.x/Configuration.h:  #define NEOPIXEL_BKGD_INDEX_FIRST   0 // Index of the first background LED  // JHG
./configuration/creality_cr10_s4_mks_mini_12864_v3/bugfix-2.1.x/Configuration.h:  #define NEOPIXEL_BKGD_COLOR { 255, 75, 0, 0 }  // R, G, B, W     // JHG - yellow
./configuration/creality_cr10_s4_mks_mini_12864_v3/bugfix-2.1.x/Configuration_adv.h:  #define LED_CONTROL_MENU    // JHG
./configuration/creality_cr10_s4_mks_mini_12864_v3/bugfix-2.1.x/Configuration_adv.h:  #define BABYSTEP_DISPLAY_TOTAL          // Display total babysteps since last G28 // JHG
./configuration/creality_cr10_s4_mks_mini_12864_v3/bugfix-2.1.x/Configuration_adv.h:  #define BABYSTEP_ZPROBE_OFFSET          // Combine M851 Z and Babystepping  // JHG
./configuration/creality_cr10_s4_mks_mini_12864_v3/bugfix-2.1.x/Configuration_adv.h:  // #define HOME_BEFORE_FILAMENT_CHANGE             // If needed, home before parking for filament change    // JHG
./configuration/creality_cr10_s4_mks_mini_12864_v3/bugfix-2.1.x/Configuration_adv.h:  #define FILAMENT_LOAD_UNLOAD_GCODES           // Add M701/M702 Load/Unload G-codes, plus Load/Unload in the LCD Prepare menu.   // JHG

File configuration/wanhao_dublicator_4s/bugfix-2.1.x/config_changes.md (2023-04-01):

./configuration/wanhao_dublicator_4s/bugfix-2.1.x/Configuration.h:    //JHG S4 Links

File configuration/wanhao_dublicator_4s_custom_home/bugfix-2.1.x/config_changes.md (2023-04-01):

./configuration/wanhao_dublicator_4s_custom_home/bugfix-2.1.x/Configuration.h:    //JHG S4 Links
./configuration/wanhao_dublicator_4s_custom_home/bugfix-2.1.x/Configuration.h:// #define Z_MIN_POS 160 //JHG
./configuration/wanhao_dublicator_4s_custom_home/bugfix-2.1.x/Configuration.h:// #define Z_MAX_POS 0 //JHG

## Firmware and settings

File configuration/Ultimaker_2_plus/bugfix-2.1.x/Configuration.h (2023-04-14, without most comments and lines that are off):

#pragma once
#define CONFIGURATION_H_VERSION 02010300
#define STRING_CONFIG_H_AUTHOR "(CoolZeroNL, default config)" // Who made the changes.    // JHG
#define SHOW_BOOTSCREEN
  #define MOTHERBOARD BOARD_ULTIMAIN_2
#define SERIAL_PORT 0
#define BAUDRATE 250000
#define BAUD_RATE_GCODE       // Enable G-code M575 to set the baud rate
#define CUSTOM_MACHINE_NAME "Ultimaker 2+"
#define X_DRIVER_TYPE  A4988
#define Y_DRIVER_TYPE  A4988
#define Z_DRIVER_TYPE  A4988
#define E0_DRIVER_TYPE A4988
#define EXTRUDERS 1
#define DEFAULT_NOMINAL_FILAMENT_DIA 2.85
#define TEMP_SENSOR_0 20
#define TEMP_SENSOR_1 0
#define TEMP_SENSOR_2 0
#define TEMP_SENSOR_3 0
#define TEMP_SENSOR_4 0
#define TEMP_SENSOR_5 0
#define TEMP_SENSOR_6 0
#define TEMP_SENSOR_7 0
#define TEMP_SENSOR_BED 20 // PT100 used for nozzle and bed in v2.0 board UM2/UMO+ https://support.ultimaker.com/hc/en-us/articles/360011640020-Stopped-temp-sensor-ER01
#define TEMP_SENSOR_PROBE 0
#define TEMP_SENSOR_CHAMBER 0
#define TEMP_SENSOR_COOLER 0
#define TEMP_SENSOR_BOARD 0
#define TEMP_SENSOR_REDUNDANT 0
#define DUMMY_THERMISTOR_998_VALUE  25
#define DUMMY_THERMISTOR_999_VALUE 100
#if TEMP_SENSOR_IS_MAX_TC(0)
  #define MAX31865_SENSOR_OHMS_0      100 // (Ω) Typically 100 or 1000 (PT100 or PT1000)
  #define MAX31865_CALIBRATION_OHMS_0 430 // (Ω) Typically 430 for Adafruit PT100; 4300 for Adafruit PT1000
#endif
#if TEMP_SENSOR_IS_MAX_TC(1)
  #define MAX31865_SENSOR_OHMS_1      100
  #define MAX31865_CALIBRATION_OHMS_1 430
#endif
#if TEMP_SENSOR_IS_MAX_TC(2)
  #define MAX31865_SENSOR_OHMS_2      100
  #define MAX31865_CALIBRATION_OHMS_2 430
#endif
#if HAS_E_TEMP_SENSOR
  #define TEMP_RESIDENCY_TIME          3  // (seconds) Time to wait for hotend to "settle" in M109
  #define TEMP_WINDOW                  2  // (°C) Temperature proximity for the "temperature reached" timer
  #define TEMP_HYSTERESIS              3  // (°C) Temperature proximity considered "close enough" to the target
#endif
#if TEMP_SENSOR_BED
  #define TEMP_BED_RESIDENCY_TIME     10  // (seconds) Time to wait for bed to "settle" in M190
  #define TEMP_BED_WINDOW              1  // (°C) Temperature proximity for the "temperature reached" timer
  #define TEMP_BED_HYSTERESIS          3  // (°C) Temperature proximity considered "close enough" to the target
#endif
#if TEMP_SENSOR_CHAMBER
  #define TEMP_CHAMBER_RESIDENCY_TIME 10  // (seconds) Time to wait for chamber to "settle" in M191
  #define TEMP_CHAMBER_WINDOW          1  // (°C) Temperature proximity for the "temperature reached" timer
  #define TEMP_CHAMBER_HYSTERESIS      3  // (°C) Temperature proximity considered "close enough" to the target
#endif
#if TEMP_SENSOR_REDUNDANT
  #define TEMP_SENSOR_REDUNDANT_SOURCE    E1  // The sensor that will provide the redundant reading.
  #define TEMP_SENSOR_REDUNDANT_TARGET    E0  // The sensor that we are providing a redundant reading for.
  #define TEMP_SENSOR_REDUNDANT_MAX_DIFF  10  // (°C) Temperature difference that will trigger a print abort.
#endif
#define HEATER_0_MINTEMP   5
#define HEATER_1_MINTEMP   5
#define HEATER_2_MINTEMP   5
#define HEATER_3_MINTEMP   5
#define HEATER_4_MINTEMP   5
#define HEATER_5_MINTEMP   5
#define HEATER_6_MINTEMP   5
#define HEATER_7_MINTEMP   5
#define BED_MINTEMP        5
#define CHAMBER_MINTEMP    5
#define HEATER_0_MAXTEMP 275
#define HEATER_1_MAXTEMP 240
#define HEATER_2_MAXTEMP 240
#define HEATER_3_MAXTEMP 240
#define HEATER_4_MAXTEMP 240
#define HEATER_5_MAXTEMP 240
#define HEATER_6_MAXTEMP 240
#define HEATER_7_MAXTEMP 240
#define BED_MAXTEMP      150
#define CHAMBER_MAXTEMP  60
#define HOTEND_OVERSHOOT 15   // (°C) Forbid temperatures over MAXTEMP - OVERSHOOT
#define BED_OVERSHOOT    10   // (°C) Forbid temperatures over MAXTEMP - OVERSHOOT
#define COOLER_OVERSHOOT  2   // (°C) Forbid temperatures closer than OVERSHOOT
#define PIDTEMP          // See the PID Tuning Guide at https://reprap.org/wiki/PID_Tuning
#define BANG_MAX 255     // Limits current to nozzle while in bang-bang mode; 255=full current
#define PID_MAX BANG_MAX // Limits current to nozzle while PID is active (see PID_FUNCTIONAL_RANGE below); 255=full current
#define PID_K1 0.99      // Smoothing factor within any PID loop
  #define PID_DEBUG             // Print PID debug data to the serial port. Use 'M303 D' to toggle activation.
    #define DEFAULT_Kp 10.38      // JHG - PID tuned - fan 100%
    #define DEFAULT_Ki 0.85       // JHG - PID tuned - fan 100%
    #define DEFAULT_Kd 31.69      // JHG - PID tuned - fan 100%
#define PIDTEMPBED
#define MAX_BED_POWER 255 // limits duty cycle to bed; 255=full current
  #define PID_BED_DEBUG // Print Bed PID debug data to the serial port.
  #define DEFAULT_bedKp 28.22     // JHG - PID tuned
  #define DEFAULT_bedKi 4.85      // JHG - PID tuned
  #define DEFAULT_bedKd 109.41    // JHG - PID tuned
#define MAX_CHAMBER_POWER 255 // limits duty cycle to chamber heater; 255=full current
  #define PID_FUNCTIONAL_RANGE 30 // If the temperature difference between the target temperature and the actual temperature
#define PREVENT_COLD_EXTRUSION
#define EXTRUDE_MINTEMP 170
#define PREVENT_LENGTHY_EXTRUDE
#define EXTRUDE_MAXLENGTH 705+35
#define THERMAL_PROTECTION_HOTENDS // Enable thermal protection for all extruders
#define THERMAL_PROTECTION_BED     // Enable thermal protection for the heated bed
#define THERMAL_PROTECTION_CHAMBER // Enable thermal protection for the heated chamber
#define THERMAL_PROTECTION_COOLER  // Enable thermal protection for the laser cooling
#define USE_XMIN_PLUG
#define USE_YMAX_PLUG   // JHG - switch is in the back, so max position
#define USE_ZMAX_PLUG   // JHG - switch is in bottom, so max position
#define ENDSTOPPULLUPS
#define X_MIN_ENDSTOP_HIT_STATE LOW
#define X_MAX_ENDSTOP_HIT_STATE LOW
#define Y_MIN_ENDSTOP_HIT_STATE LOW
#define Y_MAX_ENDSTOP_HIT_STATE LOW
#define Z_MIN_ENDSTOP_HIT_STATE LOW
#define Z_MAX_ENDSTOP_HIT_STATE LOW
#define I_MIN_ENDSTOP_HIT_STATE HIGH
#define I_MAX_ENDSTOP_HIT_STATE HIGH
#define J_MIN_ENDSTOP_HIT_STATE HIGH
#define J_MAX_ENDSTOP_HIT_STATE HIGH
#define K_MIN_ENDSTOP_HIT_STATE HIGH
#define K_MAX_ENDSTOP_HIT_STATE HIGH
#define U_MIN_ENDSTOP_HIT_STATE HIGH
#define U_MAX_ENDSTOP_HIT_STATE HIGH
#define V_MIN_ENDSTOP_HIT_STATE HIGH
#define V_MAX_ENDSTOP_HIT_STATE HIGH
#define W_MIN_ENDSTOP_HIT_STATE HIGH
#define W_MAX_ENDSTOP_HIT_STATE HIGH
#define Z_MIN_PROBE_ENDSTOP_HIT_STATE HIGH
#define DEFAULT_AXIS_STEPS_PER_UNIT   { 80, 80, 200.0, 369.0 }
#define DEFAULT_MAX_FEEDRATE          { 300, 300, 40, 45 }      // JHG - match speed to org config of the machine
#define DEFAULT_MAX_ACCELERATION      { 9000,9000,100,10000 }
#define DEFAULT_ACCELERATION                  3000  // X, Y, Z ... and E acceleration for printing moves
#define DEFAULT_RETRACT_ACCELERATION          3000  // E acceleration for retracts
#define DEFAULT_TRAVEL_ACCELERATION           3000  // X, Y, Z ... acceleration for travel (non printing) moves
#define CLASSIC_JERK
  #define DEFAULT_XJERK 20.0
  #define DEFAULT_YJERK 20.0
  #define DEFAULT_ZJERK  0.4
  #define LIMITED_JERK_EDITING          // Limit edit via M205 or LCD to DEFAULT_aJERK * 2
    #define MAX_JERK_EDIT_VALUES { 20, 20, 0.6, 10 } // ...or, set your own edit limits
#define DEFAULT_EJERK    5.0  // May be used by Linear Advance
#define S_CURVE_ACCELERATION
#define Z_MIN_PROBE_USES_Z_MIN_ENDSTOP_PIN
#define NOZZLE_TO_PROBE_OFFSET { 0, 0, 0 }
#define PROBING_TOOL 0
#define PROBING_MARGIN 5
#define XY_PROBE_FEEDRATE (133*60)
#define Z_PROBE_FEEDRATE_FAST (4*60)
#define Z_PROBE_FEEDRATE_SLOW (Z_PROBE_FEEDRATE_FAST / 2)
#define Z_CLEARANCE_DEPLOY_PROBE   10 // Z Clearance for Deploy/Stow
#define Z_CLEARANCE_BETWEEN_PROBES  5 // Z Clearance between probe points
#define Z_CLEARANCE_MULTI_PROBE     5 // Z Clearance between multiple probes
#define Z_PROBE_LOW_POINT          -2 // Farthest distance below the trigger-point to go before stopping
#define Z_PROBE_OFFSET_RANGE_MIN -15
#define Z_PROBE_OFFSET_RANGE_MAX -5
#define X_ENABLE_ON 0
#define Y_ENABLE_ON 0
#define Z_ENABLE_ON 0
#define E_ENABLE_ON 0 // For all extruders
#define DISABLE_OTHER_EXTRUDERS   // Keep only the active extruder enabled
#define INVERT_X_DIR true
#define INVERT_Y_DIR false
#define INVERT_Z_DIR true
#define INVERT_E0_DIR true
#define INVERT_E1_DIR false
#define INVERT_E2_DIR false
#define INVERT_E3_DIR false
#define INVERT_E4_DIR false
#define INVERT_E5_DIR false
#define INVERT_E6_DIR false
#define INVERT_E7_DIR false
#define Z_AFTER_HOMING  10        // (mm) Height to move to after homing Z
#define X_HOME_DIR -1
#define Y_HOME_DIR 1     // JHG - Homing is now moving to the front, switch is in the back
#define Z_HOME_DIR 1     // JHG - Homing is now moving to the top, switch is in the bottom
#define X_BED_SIZE 223      // JHG - 220 to 223.0 cura profile size
#define Y_BED_SIZE 223      // JHG - 220 to 223.0 cura profile size
#define X_MIN_POS 0
#define Y_MIN_POS 0
#define Z_MIN_POS 0
#define X_MAX_POS X_BED_SIZE
#define Y_MAX_POS Y_BED_SIZE
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

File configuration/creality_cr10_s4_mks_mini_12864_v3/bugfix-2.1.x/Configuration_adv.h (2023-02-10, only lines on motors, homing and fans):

#define E0_AUTO_FAN_PIN -1
#define E1_AUTO_FAN_PIN -1
#define E2_AUTO_FAN_PIN -1
#define E3_AUTO_FAN_PIN -1
#define E4_AUTO_FAN_PIN -1
#define E5_AUTO_FAN_PIN -1
#define E6_AUTO_FAN_PIN -1
#define E7_AUTO_FAN_PIN -1
#define CHAMBER_AUTO_FAN_PIN -1
#define COOLER_AUTO_FAN_PIN -1
#define HOMING_BUMP_MM      { 5, 5, 2 }       // (linear=mm, rotational=°) Backoff from endstops after first bump
#define HOMING_BUMP_DIVISOR { 2, 2, 4 }       // Re-Bump Speed Divisor (Divides the Homing Feedrate)
#define QUICK_HOME                            // If G28 contains XY do a diagonal move first
#define MICROSTEP_MODES { 16, 16, 16, 16, 16, 16 } // [1,2,4,8,16]
#define ADVANCED_OK
#define ADVANCED_PAUSE_FEATURE
  #define ADVANCED_PAUSE_CONTINUOUS_PURGE         // Purge continuously up to the purge length until interrupted.
  #define ADVANCED_PAUSE_PURGE_FEEDRATE        3  // (mm/s) Extrude feedrate (after loading). Should be slower than load feedrate.
  #define ADVANCED_PAUSE_PURGE_LENGTH        150  // (mm) Length to extrude after loading.
  #define ADVANCED_PAUSE_RESUME_PRIME          0  // (mm) Extra distance to prime nozzle after returning from park.
  #define HOME_BEFORE_FILAMENT_CHANGE             // If needed, home before parking for filament change

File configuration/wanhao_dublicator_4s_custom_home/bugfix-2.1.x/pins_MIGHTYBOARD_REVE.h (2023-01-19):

/**
 * Marlin 3D Printer Firmware
 * Copyright (c) 2020 MarlinFirmware [https://github.com/MarlinFirmware/Marlin]
 *
 * Based on Sprinter and grbl.
 * Copyright (c) 2011 Camiel Gubbels / Erik van der Zalm
 *
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
 */
#pragma once

/**
 * Mightyboard Rev.E pin assignments
 * also works for Rev D boards. It's all rev E despite what the silk screen says
 */

/**
 * Rev B  2 JAN 2017
 *
 *  Added pin definitions for:
 *    M3, M4 & M5 spindle control commands
 *    case light
 *
 *  Corrected pin assignment for EX2_HEAT_PIN pin. Changed it from 9 to 11.  The port
 *  number (B5) agrees with the schematic but B5 is assigned to logical pin 11.
 */

#define ALLOW_MEGA1280
#include "env_validate.h"

#define BOARD_INFO_NAME      "Mightyboard"
#define DEFAULT_MACHINE_NAME "MB Replicator"

//
// Servos
//
#define SERVO0_PIN                            36  // C1 (1280-EX1)
#define SERVO1_PIN                            37  // C0 (1280-EX2)
#define SERVO2_PIN                            40  // G1 (1280-EX3)
#define SERVO3_PIN                            41  // G0 (1280-EX4)

//
// Limit Switches
//
#define X_MIN_PIN                             49  // L0
#define X_MAX_PIN                             48  // L1
#define Y_MIN_PIN                             47  // L2
#define Y_MAX_PIN                             46  // L3
#define Z_MIN_PIN                             43  // L6
#define Z_MAX_PIN                             42  // L7

//
// Z Probe (when not Z_MIN_PIN)
//
#ifndef Z_MIN_PROBE_PIN
  #define Z_MIN_PROBE_PIN                     42
#endif

//
// Filament Runout Sensor
//
#ifndef FIL_RUNOUT_PIN
  #define FIL_RUNOUT_PIN                      49
#endif
#ifndef FIL_RUNOUT2_PIN
  #define FIL_RUNOUT2_PIN                     47
#endif

//
// Steppers
//
#define X_STEP_PIN                            55  // F1
#define X_DIR_PIN                             54  // F0
#define X_ENABLE_PIN                          56  // F2

#define Y_STEP_PIN                            59  // F5
#define Y_DIR_PIN                             58  // F4
#define Y_ENABLE_PIN                          60  // F6

#define Z_STEP_PIN                            63  // K1
#define Z_DIR_PIN                             62  // K0
#define Z_ENABLE_PIN                          64  // K2

#define E0_STEP_PIN                           25  // A3
#define E0_DIR_PIN                            24  // A2
#define E0_ENABLE_PIN                         26  // A4

#define E1_STEP_PIN                           29  // A7
#define E1_DIR_PIN                            28  // A6
#define E1_ENABLE_PIN                         39  // G2

//
// I2C Digipots - MCP4018
// Address 5E (2F << 1)
// Set from 0 - 127 with stop bit.
// (Ex. 3F << 1 | 1)
//
#define DIGIPOTS_I2C_SCL                      76  // J5
#define DIGIPOTS_I2C_SDA_X                    57  // F3
#define DIGIPOTS_I2C_SDA_Y                    61  // F7
#define DIGIPOTS_I2C_SDA_Z                    65  // K3
#define DIGIPOTS_I2C_SDA_E0                   27  // A5
#define DIGIPOTS_I2C_SDA_E1                   77  // J6

#ifndef DIGIPOT_I2C_ADDRESS_A
  #define DIGIPOT_I2C_ADDRESS_A             0x2F  // unshifted slave address (5E <- 2F << 1)
#endif
#define DIGIPOT_ENABLE_I2C_PULLUPS                // MightyBoard doesn't have hardware I2C pin pull-ups.

//
// Temperature Sensors
//
// K7 - 69 / ADC15 - 15
#define TEMP_BED_PIN                          15

// SPI for MAX Thermocouple
// Uses a separate SPI bus
//
//  3 E5 DO (SO)
//  5 E3 CS1
//  2 E4 CS2
// 78 E2 SCK
//
#define TEMP_0_CS_PIN                          5  // E3
#define TEMP_0_SCK_PIN                        78  // E2
#define TEMP_0_MISO_PIN                        3  // E5
//#define TEMP_0_MOSI_PIN                    ...  // For MAX31865

#define TEMP_1_CS_PIN                          2  // E4
#define TEMP_1_SCK_PIN            TEMP_0_SCK_PIN
#define TEMP_1_MISO_PIN          TEMP_0_MISO_PIN
//#define TEMP_1_MOSI_PIN        TEMP_0_MOSI_PIN

//
// FET Pin Mapping - FET 1 is closest to the input power connector
//
#define MOSFET_1_PIN                           6  // Plug EX1 Pin 1-2 -> PH3 #15 -> Logical 06
#define MOSFET_2_PIN                           7  // Plug EX1 Pin 3-4 -> PH4 #16 -> Logical 07
#define MOSFET_3_PIN                          11  // Plug EX2 1-2 -> PB5 #24 -> Logical 11
#define MOSFET_4_PIN                          12  // Plug EX2 3-4 -> PB6 #25 -> Logical 12
#define MOSFET_5_PIN                          45  // Plug HBD 1-2 -> PL4 #39 -> Logical 45
#define MOSFET_6_PIN                          44  // Plug Extra 1-2 -> PL5 #40 -> Logical 44 (FET not soldered in all boards)

//
// Heaters / Fans (24V)
//
#define HEATER_0_PIN                MOSFET_1_PIN // EX1
#define HEATER_1_PIN                MOSFET_3_PIN // EX2
#define HEATER_BED_PIN              MOSFET_5_PIN // HBP

// User Fans
#ifdef NUM_M106_FANS
  #define FAN_PIN MOSFET_6_PIN                    //Print cooling fan on Extra Plug
#endif
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

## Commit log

2022-12-04 enable babysteps for S4
    [Configuration_adv.h]
2022-12-10 max height to 160 for S4
    [Configuration.h]
2022-12-11 (2022-12-08) for S4
    [Configuration.h]
2023-01-17 extruder offset -34 to -33
    [Configuration.h]
2023-01-18 extruder offset -33 to -33.1
    [Configuration.h]
2023-01-18 extruder offset -33.1 to -32.9
    [Configuration.h]
2023-01-19 set NUM_M106_FANS to 1
    [Configuration.h]
2023-01-19 add custom pins file, and add NUM_M106_FANS to enable it for Mostfet6 to use the extra pinheader for FAN
2023-01-25 add init config for creality S4
    [Configuration.h, Configuration_adv.h]
2023-01-25 correct board
2023-01-26 copy setting of current firmware into this config.h file
    [Configuration.h, Configuration_adv.h]
2023-01-26 enable, z_safe_homing
    [Configuration.h]
2023-01-28 finetune config for cr10-s4
    [Configuration.h, Configuration_adv.h]
2023-01-29 probe marge 0 and bed size to 360 (limit switch 20mm moved to the front)
    [Configuration.h]
2023-01-29 zet probe offzet
    [Configuration.h]
2023-01-29 add INDIVIDUAL_AXIS_HOMING_MENU
    [Configuration.h]
2023-01-29 add marge z probe 10mm
    [Configuration.h]
2023-01-29 add points for probe to 4x4
    [Configuration.h]
2023-01-29 add marlin left for probe 40
    [Configuration_adv.h]
2023-02-10 add CR10 + MKS v3 LCD
    [Configuration.h, Configuration_adv.h]
2023-02-10 change neo type
    [Configuration.h]
2023-02-10 change neo stuff
    [Configuration.h]
2023-03-05 4s & 4s with custom Y home switch in the from
    [Configuration.h, Configuration_adv.h, Wanhao-dub-D6-switchholder v3.f3d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]
2023-03-22 cr10 - bltoutch
    [Configuration.h]
2023-04-14 adjust size
    [Configuration.h]
2023-04-14 adjust Homing dir
    [Configuration.h]
2023-04-14 set same of higher speed rates
    [Configuration.h]
2023-04-14 correct PID numbers of machine
    [Configuration.h]
2023-04-14 pid debug enabled
    [Configuration.h]

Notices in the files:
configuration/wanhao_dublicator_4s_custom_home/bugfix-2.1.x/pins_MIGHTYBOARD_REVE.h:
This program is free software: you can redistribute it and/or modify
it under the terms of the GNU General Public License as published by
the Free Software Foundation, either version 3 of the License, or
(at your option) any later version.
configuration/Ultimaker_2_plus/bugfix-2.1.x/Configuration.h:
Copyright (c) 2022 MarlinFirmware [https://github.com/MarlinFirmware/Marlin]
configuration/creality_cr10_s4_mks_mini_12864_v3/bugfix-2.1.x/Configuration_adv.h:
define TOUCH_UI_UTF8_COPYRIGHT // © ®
